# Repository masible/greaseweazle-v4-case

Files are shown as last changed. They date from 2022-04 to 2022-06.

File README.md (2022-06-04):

# Greaseweazle v4 case

Case for Greaseweazle v4 and 3.5" floppy drive by hadessuk.

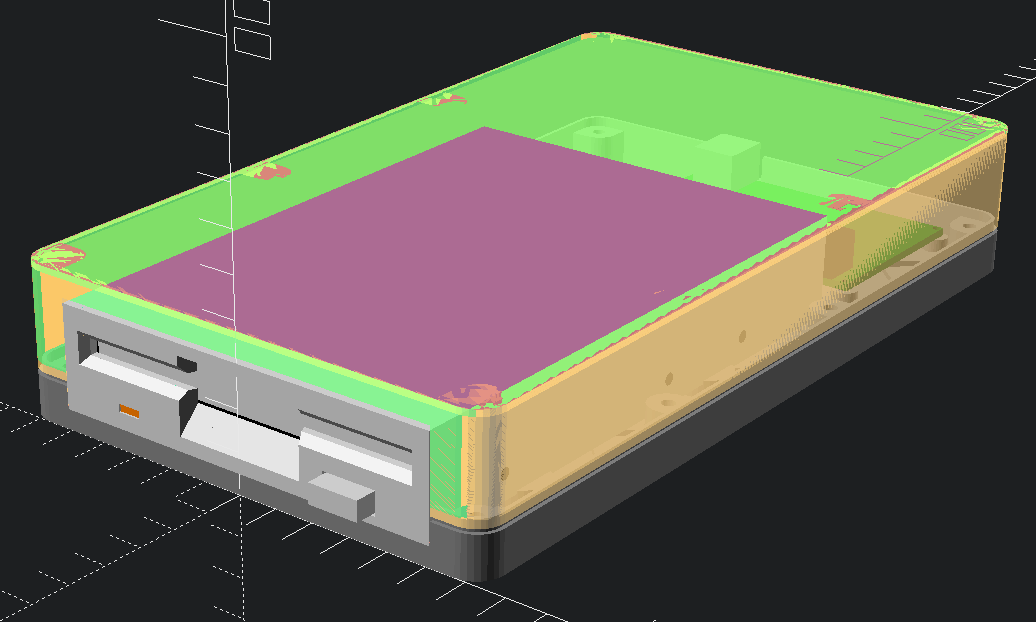
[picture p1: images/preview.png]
preview


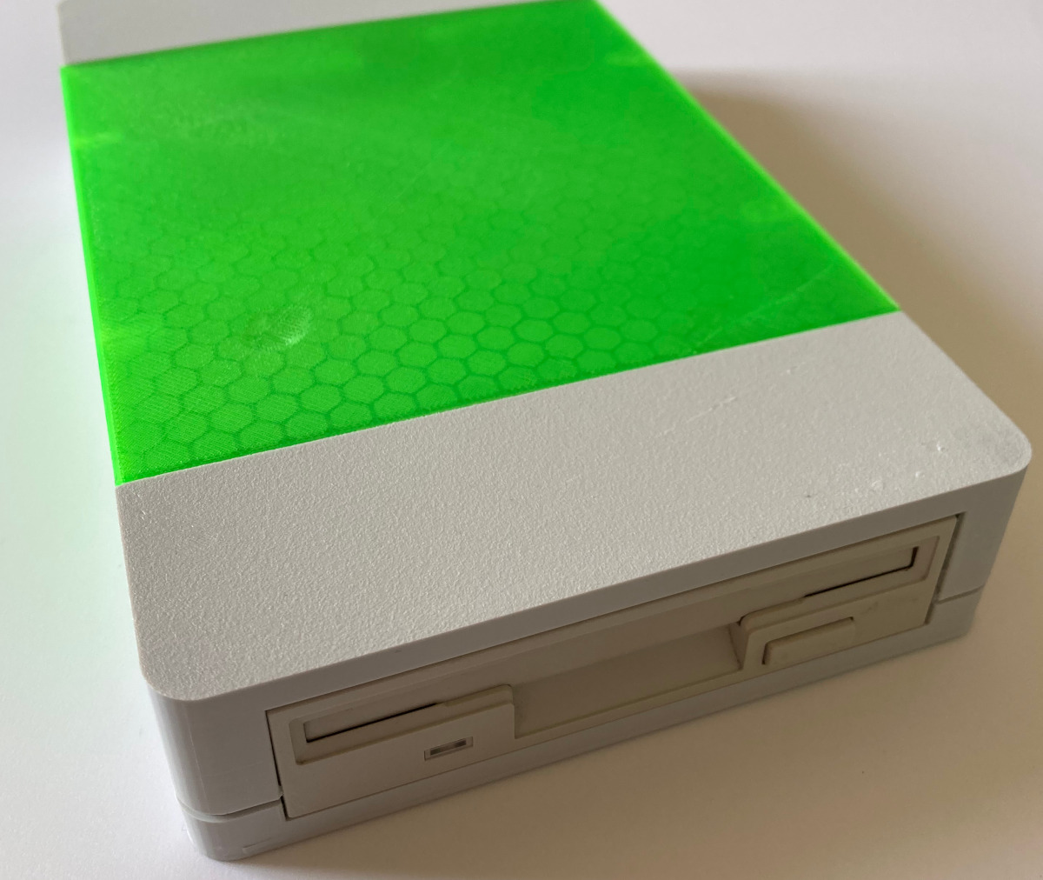
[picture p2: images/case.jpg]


### Parts

Knurled brass threaded inserts:

- 8 x M3x5 (for the case)
- 4 x M2x5 (for the Greaseweazle)

Bolts:

- 8 x M3x10 hex (for the case)
- 4 x M2x4 hex (for the Greaseweazle)
- 4 x M3x5 Phillips (to mount drive)

To complete the device, you will also need a working 3.5" drive, a floppy drive
ribbon cable, and either jumper cables or a cable with a Berg connector, and
a [Greaseweazle v4](https://www.sordan.ie/product/1003/greaseweazle-v4-usb-floppy-adapter-flux-reader-writer/).

This case requires the drive to be powered by the Greaseweazle, and makes no
accommodation for drives that require too much power or 12V.

### STL files

STL files are [available on Printables.com](https://www.printables.com/model/219991-case-for-greaseweazle-v4-and-35-floppy-drive).

You can also generate them on Unix systems if `openscad` is in your `PATH` by running `make`.

### Model variants

2 different set of models exist.

- the simplest are the `big-*` files. One model for the top and one model for
the bottom of the drive case. This requires a printer that can print at least 22cm x 14cm.
- the more complicated `small-*` models use 2 parts for the bottom case, and 3
parts for the top case. The top case is split in 3 and can be printed in different
materials to give it that striped look. This requires a 15cm x 15cm printer.

If your printer is big enough, you can of course use the single bottom plate with
the "small" top case models. The back and front of the small variant of the top case can usually be
printed, sequentially, in one sitting, even on a small printer.

### Known problems

- The "small" top case flexes a bit too much and could do with having a lip that prevents this.
- The holes for mounting the Greaseweazle are a bit too unforgiving when brass inserts are mounted.
- The USB port hole could be moved left to accommodate shorter ribbon cables.
- The holes in the bottom case are ever so slightly too tight for common hex head screws.

### License

Based on [Greaseweazle F7 Lightning Plus case](https://www.thingiverse.com/thing:4920473)
by [n13ldo](https://www.thingiverse.com/n13ldo), itself based on
[Case for Greaseweazle F7 and 3.5" floppy drive](https://www.thingiverse.com/thing:4423258/)
by [ali1234](https://www.thingiverse.com/ali1234).

Licensed under [CC BY 4.0](https://creativecommons.org/licenses/by/4.0/).

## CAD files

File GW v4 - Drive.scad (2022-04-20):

drive_width = 101.6;
drive_height = 25.4;
drive_depth = 150;




module bottom_holes_y() {
    translate([0, 35]) children();
    translate([0, 105]) children();
}

module bottom_holes() {
    translate([3.7 - drive_width/2, 0]) bottom_holes_y() children();
    translate([drive_width/2 - 3.7, 0]) bottom_holes_y() children();
}

module side_holes_y() {
    translate([0, 25]) children();
    translate([0, 85]) children();
    translate([0, 115]) children();
}

module side_holes() {
    
    translate([0, 0, 6.35]) {
        translate([drive_width/2, 0])rotate([0, 90, 0]) side_holes_y() children();
        translate([-drive_width/2, 0]) rotate([0, -90, 0]) side_holes_y() children();
    }
}



module diskslot() {
    translate([0, 0, 16]) {
        translate([0, 4]) cube([90, 4, 4], center=true);
        hull() {
            translate([0, 1]) cube([90, 2.1, 4], center=true);
            translate([0, -1]) cube([94, 1, 9], center=true);
        }
    }
    
    translate([0, 0, 12.7]) {
        hull() {
            translate([0, 4.1, 3.3]) cube([29, 2, 7], center=true);
            translate([0, -1]) cube([34, 1, 20], center=true);
        }
    }
}


module bezel(colour="beige") {
    color(colour) {
        difference() {
            translate([-drive_width/2, 0]) cube([drive_width, 4.01, drive_height]);
            diskslot();
            translate([30, 0, 5]) cube([14, 10, 6], center=true);
            translate([-32, 0, 5]) cube([6, 10, 2], center=true);
        }
        translate([30, 0, 5]) cube([13, 10, 5], center=true);
        translate([0, 5, 16]) cube([90, 1, 10], center=true);
        
    }
    color([1, 0.5, 0]) translate([-32, 1, 5]) cube([6, 1, 2], center=true);
}


module drive(colour="beige") {
    
    difference() {
        translate([-drive_width/2, 4]) color("lightgrey") cube([drive_width, drive_depth-4, drive_height]);
        translate([-drive_width/2 + 1, 3, 1]) color([0, 0, 0]) cube([drive_width-2, drive_depth-4, drive_height-2]);
        color("black") {
            
            bottom_holes() cylinder(d=3, h=10, center=true);
            side_holes() cylinder(d=3, h=10, center=true);
        }
    }
    bezel(colour);
}


module drive_block() {
    difference() {
        translate([-(drive_width+0.4)/2, -1, -0.2]) cube([drive_width+0.4, drive_depth+1, drive_height+0.4]);
    }
}

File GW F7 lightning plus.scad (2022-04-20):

// Case for Greaseweazle F7 board and 3.5" floppy drive
// License: CC BY-SA 4.0

use <GW F7 lightning plus - Box.scad>;
use <GW F7 lightning plus - GW.scad>;
include <GW F7 lightning plus - Drive.scad>;

$fn = 32;
drive_width = 101.6;
drive_height = 25.4;
drive_depth = 150;
distance_drive_to_back = 68;

module gw_pos() {
    translate([18, 183, 0]) children();
}

module cutouts() {
    
    // Floppy drive port
    translate([0,0,6]) drive_block();

    // USB port
    translate([42, drive_depth + distance_drive_to_back, 12.5]) cube([12.5, 12, 12], center=true);
}

module case_top() { 
    difference() {
        translate([0, 0, drive_height+12.2]) mirror([0, 0, 1])
            translate([0, (drive_depth + distance_drive_to_back)/2])
                top([drive_width+27, drive_depth + distance_drive_to_back], 7, [2, 4], height=drive_height-1, thickness=1.6, brace=false);
        cutouts();
    }
}

module case_bottom() {
    difference() {
        union() {
            translate([0, (drive_depth + distance_drive_to_back)/2])
                bottom([drive_width+27, drive_depth + distance_drive_to_back], 7, [2, 4], height=11, thickness=1.6);
            bottom_holes() cylinder(d=14, h=5.8);            
        }
 
        translate([0, 0, -0.1]) bottom_holes() {
            cylinder(d=8, h=4);
            cylinder(d=3.8, h=7);
        }
        
        cutouts();
    }
   
    difference() {
        gw_pos() gw_holes() cylinder(d=6.5, h=5);
        translate([0, 0, 2]) gw_pos() gw_holes() cylinder(d=3.2, h=5);
    }
}

// Include the floppy drive model
//translate([0, -0.1, 5]) drive(colour="lightgrey");

intersection() {
    union() {
        
        // Case - bottom
        color("grey", 1) case_bottom();
        
        // Case - top
        color("orange", 0.5) case_top();
    }
}

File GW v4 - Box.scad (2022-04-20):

// box

$fn=32;


module mirrorkeep(x) {
    children();
    mirror(x) children();
}


module offset_diff(d) {
    difference() {
        offset(d[0]) children();
        offset(d[1]) children();
    }
}


module fill() {
    for (i = [-10:10]) {
        translate([0, i*30]) square([500, 1.2], center=true);
    }
}


module shell(height, thickness, wall, top, gap=1, brace=true) {
    linear_extrude(height=thickness, convexity=2) children();
    linear_extrude(height=height-(gap/2), convexity=2) offset_diff([0, -wall]) children();
    linear_extrude(height=height+(top?2-(gap/2):2+(gap/2)), convexity=2)
        offset_diff(top ? [0, 0.1-wall/2] : [-wall/2, -wall]) children();
    
    if (brace) linear_extrude(height=3, convexity=4) intersection() {
        union() {
            rotate(45) fill();
            rotate(-45) fill();
        }
        children();
    }
}


module outline(size, radius) {
    offset(radius) offset(-radius) square(size, center=true);
}




module screw_pos(size, offset, screws) {
    p = [for (i = size) (i - (offset*2))];
    n = screws[0] - 1;
    for (i = [0:n]) {
        x = n == 0 ? 0 : (i/n) - 0.5;
        mirrorkeep([0, 1]) translate([x*p[0], 0.5*p[1]]) rotate(90) children();
    }
    m = screws[1] - 1;
    for (i = [0:m]) {
        x = m == 0 ? 0 : (i/m) - 0.5;
        mirrorkeep([1, 0]) translate([0.5*p[0], x*p[1]]) children();
    }
}


module bottom(size, radius, screws, height, thickness=1, wall=2, brace=true) {
    difference() {
        union() {
            shell(height, thickness, wall, false) outline(size, radius);
            linear_extrude(height=height, convexity=5) intersection() {
                offset(-(wall/2)-0.1)outline(size, radius);
                union() {
                    screw_pos(size, radius, screws) hull() {
                        circle(r=radius-wall);
                        translate([radius*2, 0]) circle(r=radius-wall+0.5);
                    }
                }
            }
        }
        translate([0, 0, -0.1]) screw_pos(size, radius, screws) {
            cylinder(d=6.0, h=height-4);
            cylinder(d=3.4, h=height+1);
        }
    }
}


module top(size, radius, screws, height, thickness=1, wall=2, brace=true) {
    difference() {
        union() {
            shell(height, thickness, wall, true, brace=brace) outline(size, radius);
            linear_extrude(height=height-0.5, convexity=5) intersection() {
                offset(-wall/2) outline(size, radius);
                union() {
                    screw_pos(size, radius, screws) hull() {
                        circle(r=radius-wall);
                        translate([radius*2, 0]) circle(r=radius-wall+0.5);
                    }
                }
            }
            linear_extrude(height=height+2, convexity=5) intersection() {
                offset(-wall-0.1) outline(size, radius);
                union() {
                    screw_pos(size, radius, screws) hull() {
                        circle(r=radius-wall);
                        translate([radius*2, 0]) circle(r=radius-wall+0.5);
                    }
                }
            }            
        }
        translate([0, 0, height-5]) screw_pos(size, radius, screws) {
            cylinder(d=4, h=height);
            translate([0, 0, -2]) cylinder(d=2.5, h=height);
        }
    }
}


module all(size, radius, screws, height, thickness=1, wall=2) {
    top(size, radius, screws, height, thickness, wall);
    translate([size[0]+10, 0]) bottom(size, radius, screws, height, thickness, wall);
}


all([150, 250], 7, [3, 4], 10, 0.8, 2);

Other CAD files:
GW v4 - GW.scad
GW v4.scad

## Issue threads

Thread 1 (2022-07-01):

Update size of inserts

hadess, 2022-07-01:
The inserts listed in the description are probably wrong for the tiny tiny mounting holes in the Greaseweazle v4, will need to update.

hadess, 2022-07-02:
The size of the inserts is correct.

Closed 2022-07-02.

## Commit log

2022-04-20 greaseweazle-v4-case
    Import models from https://www.thingiverse.com/thing:4920473
    [GW F7 lightning plus - Box.scad, GW F7 lightning plus - Drive.scad, GW F7 lightning plus - GW.scad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]
2022-04-20 Convert to Unix format
    [GW F7 lightning plus - GW.scad, GW F7 lightning plus.scad]
2022-04-20 Update filenames for future changes
    [GW v4 - Box.scad, GW v4 - Drive.scad, GW v4 - GW.scad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]
2022-04-20 Update main model description for future changes
    [GW v4.scad]
2022-04-20 Update Greaseweazle model for v4 variant
    [GW v4 - GW.scad]
2022-04-20 Optionally show Greaseweazle in main model
    [GW v4.scad]
2022-04-20 Place GW correctly in case, move cutout
    [GW v4.scad]
2022-05-06 Make GW screw posts smaller
    Otherwise the screws won't fit in the board
    [GW v4.scad]
2022-05-06 Correct GW board dimensions, screwholes and USB positions
    [GW v4 - GW.scad]
2022-05-06 Correct USB port cutout
    [GW v4.scad]
2022-05-06 fixup! Correct GW board dimensions, screwholes and USB positions
    [GW v4 - GW.scad]
2022-05-27 Correct GW dimensions again from Gerber measurements
    [GW v4 - GW.scad]
2022-05-28 Make holes for knurled brass inserts bigger
    [GW v4.scad]
2022-06-02 Add modules for generating smaller models
    For printers with smaller beds.
    [GW v4.scad]
2022-06-02 Add Makefile to automate STL generation
2022-06-04 Add placeholder for Printables link
2022-06-04 Add link to Printables page
